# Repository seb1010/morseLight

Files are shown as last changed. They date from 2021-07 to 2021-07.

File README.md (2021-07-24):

# Text to Morse Code

## Project Overview

In this project I made a light blink in morse code. You are able to write to a text file and the corresponding morse code can be programmed into the memory of a microcontroller. PWM was used to when turning on and off light for smooth transitions. Input length was restricted by the program memory of the microcontroller. There is also a switch to turn off the morse code and keep the light on all the time.

## Implementation
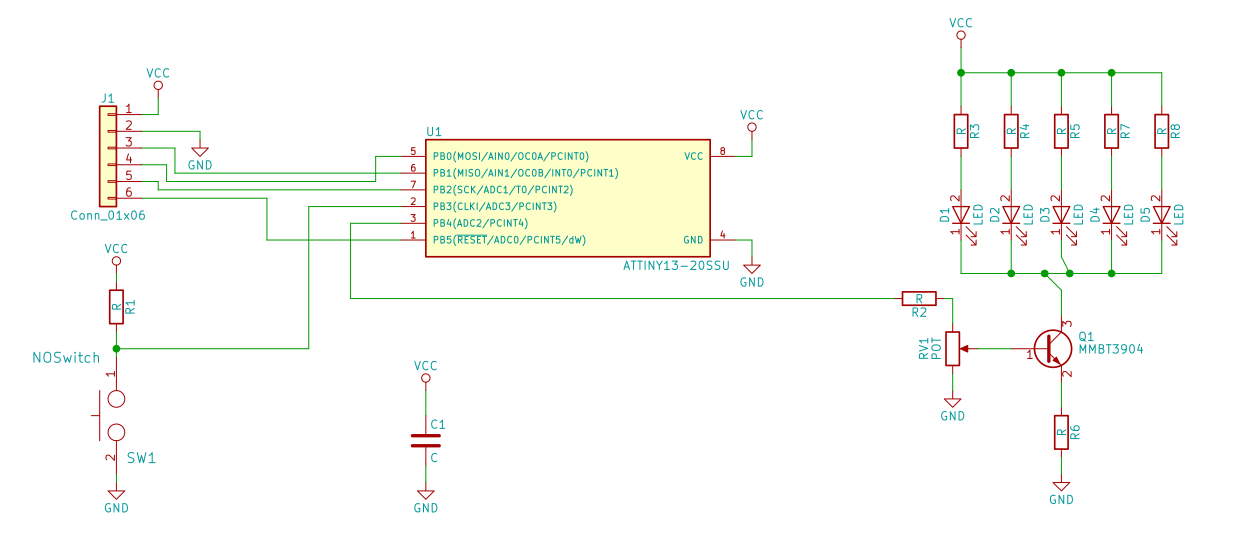
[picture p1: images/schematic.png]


### Microcontroller
**Name:** ATTiny13
**Memory:** 1k of program memory

### Programming Languages Used
* C
    * Converting text to a binary code (morse code), expressed as hex in a ascii file.
    * `textToMorse.c`
    * This output file can be read directly by the assembler I used (avra)
    * The assembler writes the binary code into the program memory

* Assembly (for ATTiny13)
    * loads one byte at a time from the program memory
    * then sends one bit at a time to a pin using PWM to soften transitions
    * `morseOut.asm`
    * Pulse with Modulation(PWM): microcontroller has built in PWM
        * Accidentally chose pins with no built in PWM
        * To remedy this, implemented PWM in software

### Dimming
* I wanted to be able to control the maximum brightness of the light so it could be used durring the day or at night.
* With only 8 bits of PWM on the microcontroller this would be impossible to achieve while keeping the transitions looking smooth even at low brightnesses. 
* This is why I included the potentiometer and transitor
* It isn't a perfect circuit as it is tempurature sensitive and sensitive to changes in supply voltage, but I wasn't able to notice these issues when using the light.

### PCB
I etched the PCB at home. Mixed through-hole and surface mount parts. 

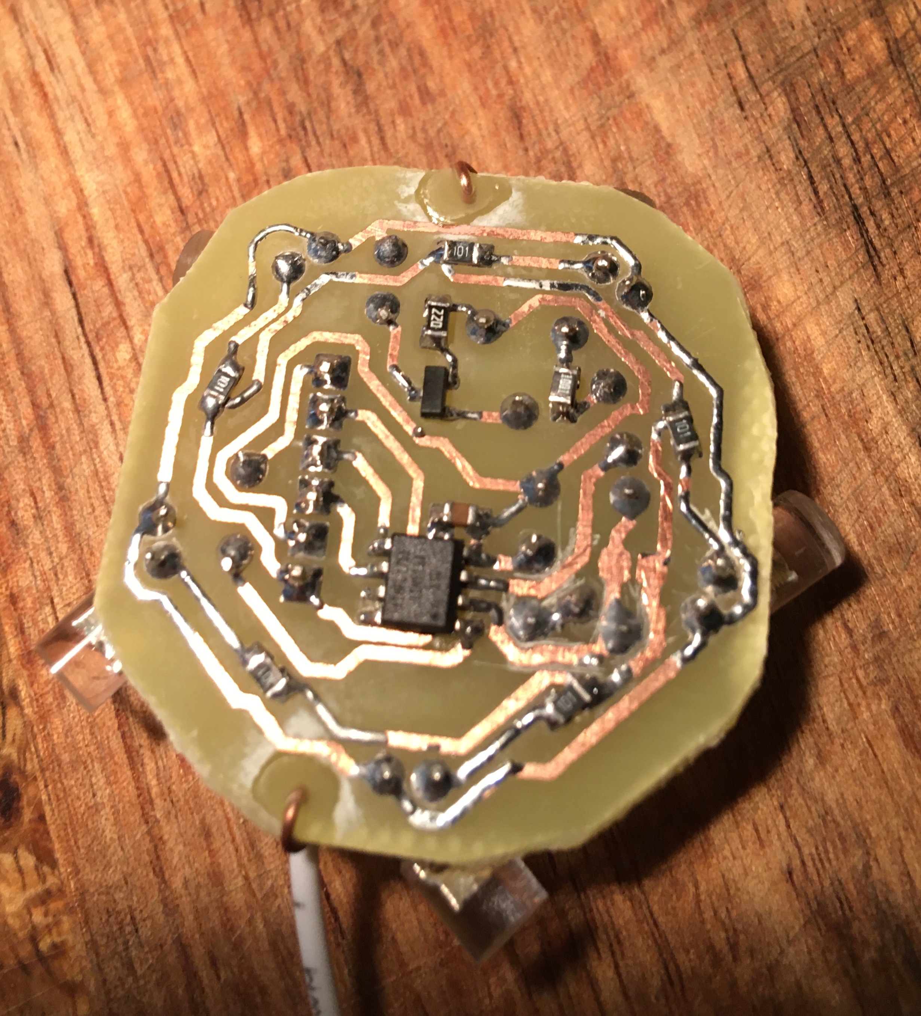
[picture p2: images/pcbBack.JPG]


#### Components
* 1 transistor
* 5 LED's
* 1 potentiometer

## Project Result and Takeaways

### Results
* It worked ok. Storing morse code the way I did was not space efficient for long messages. Also the c program was very sensitive to white space, so you have to be carful with formatting. That could definitly use improvement.

* [Video of Light Blinking on YouTube](https://youtu.be/B2VOs5uNV_o)

### Takeaways
I wish I had included reverse polarity protection.
I created the pcb before finishing the code. However, there was no need for this. I could have got the circuit woringing on a breadboard before making the PCB and this would have prevented the mistake of using the wrong pin to control the leds. Alternativily I could have been more careful and not assumed all pins had PWM capability.

If I were to do this project again I would modify the pcb instead of software to deal with PWM error. I knew I was only making one so it seemed like a more eligant solution to keep the pcb intact, but now I dont think that was the best option. 
Its nice to have different programs to integrate.

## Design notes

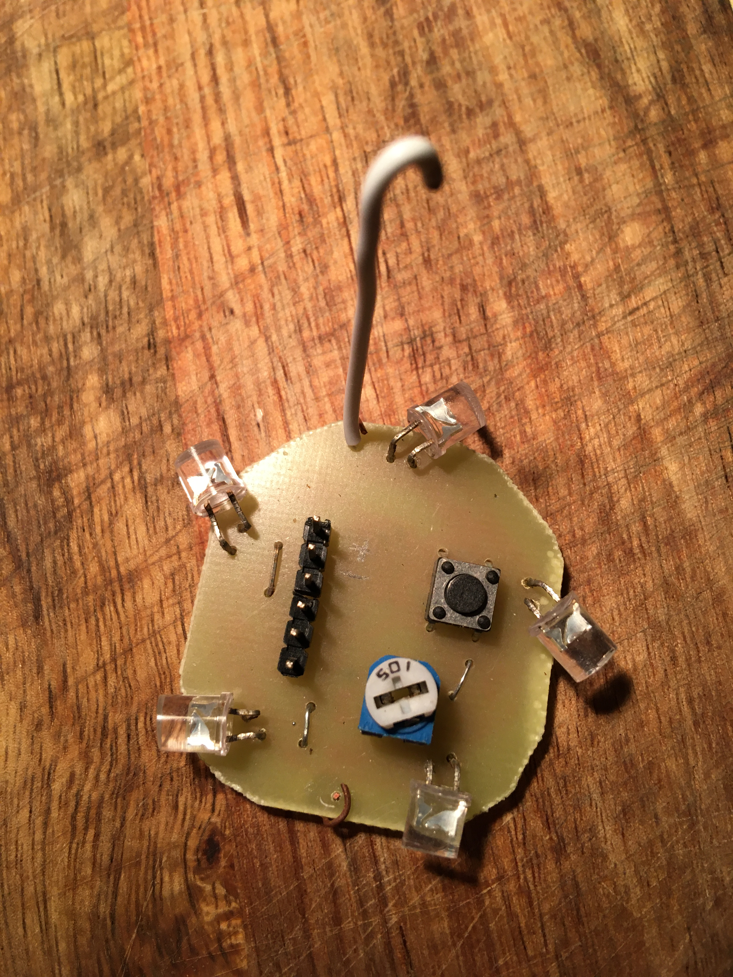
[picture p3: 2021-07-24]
images/pcbFront.JPG

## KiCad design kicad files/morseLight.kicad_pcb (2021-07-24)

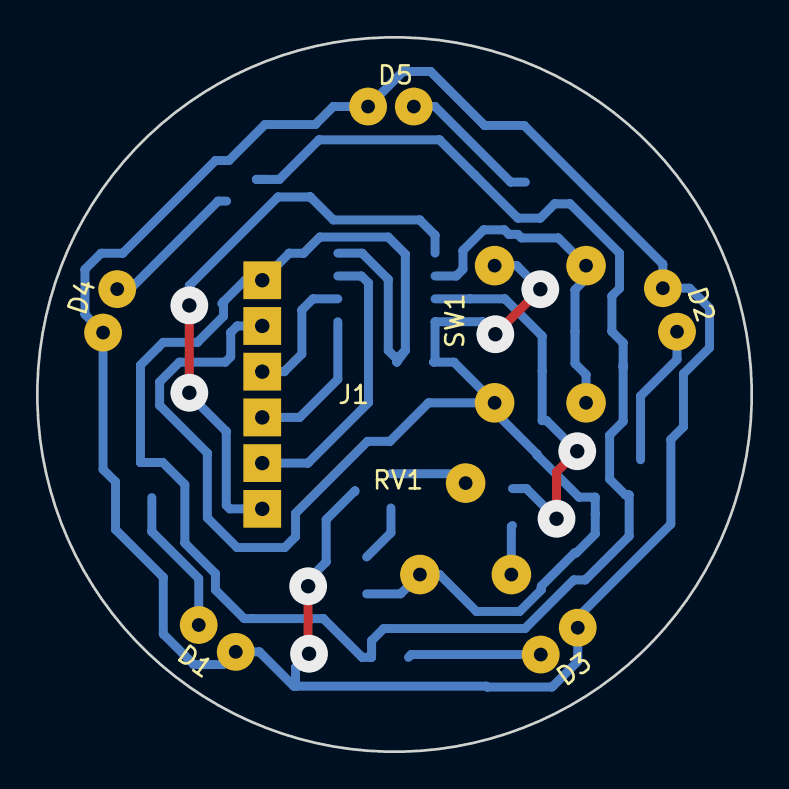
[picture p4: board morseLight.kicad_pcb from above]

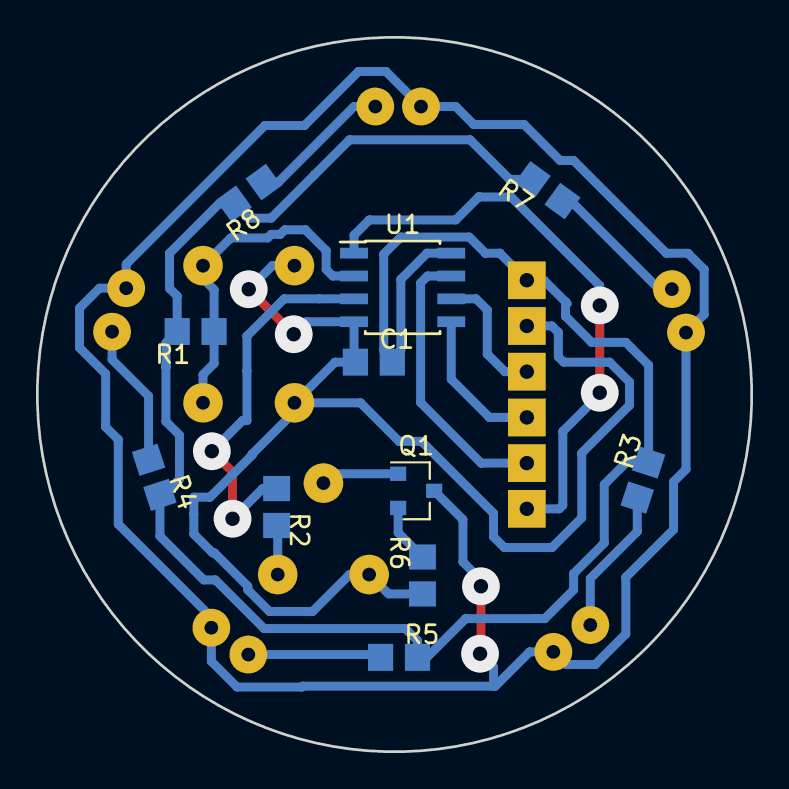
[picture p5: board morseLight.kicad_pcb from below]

Board: 2 copper layers, 39.7 x 39.7 mm, 19 parts (11 on the bottom side), 17 nets.

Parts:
C1: C; 0805_2
D1, D2, D3, D4, D5: LED; 5mmLed
J1: Conn_01x06; 6pinConn
Q1: MMBT3904; SOT-23
R1, R2, R3, R4, R5, R6, R7, R8: R; 0805_2
RV1: POT; bluePot
SW1: NOSwitch; SmollSwitch
U1: ATTINY13-20SSU; SOIC-8_3.9x4.9mm_Pitch1.27mm

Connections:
GND: C1.2, J1.2, R6.2, RV1.3, SW1.2, U1.4
unnamed: D1.1, D2.1, D3.1, D4.1, D5.1, Q1.3
unnamed: D1.2, R3.2
unnamed: D2.2, R4.2
unnamed: D3.2, R5.2
unnamed: D4.2, R7.2
unnamed: D5.2, R8.2
unnamed: J1.3, U1.6
unnamed: J1.4, U1.5
unnamed: J1.5, U1.7
unnamed: J1.6, U1.1
unnamed: Q1.1, RV1.2
unnamed: Q1.2, R6.1
unnamed: R1.2, SW1.1, U1.2
unnamed: R2.1, RV1.1
unnamed: R2.2, U1.3
VCC: C1.1, J1.1, R1.1, R3.1, R4.1, R5.1, R7.1, R8.1, U1.8
